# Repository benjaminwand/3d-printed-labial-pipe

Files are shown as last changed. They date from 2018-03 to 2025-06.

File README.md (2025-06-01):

# 3d-printed labial pipe

This is a collection of FreeCAD and OpenSCAD files that will help you to 3D-print a part of a labial pipe, to be used with a piece of tube. 

## Howto
This is how to go from here:
1. pick a file
2. choose and add measurements
3. export .stl
4. print. 

### Versions
Not necessarily the latest file is the one you want. Every 0.x has distinct features and then follow bugfixes. Please look at the images below to choose a pipe you want.

0.1 First attempt for pipes with 60mm diameter, made with tinkercad.com , here for sentimental reasons <br>
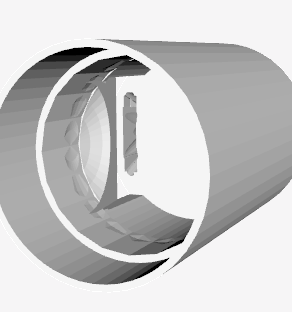
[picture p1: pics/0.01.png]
<br>
0.2 Fully proportional pipe part as FreeCAD file <br>
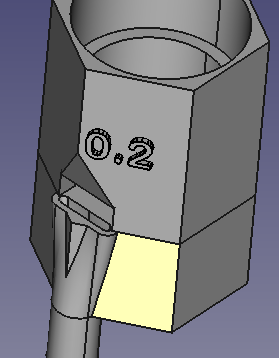
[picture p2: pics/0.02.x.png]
<br>
0.2.3 Bug fixes, mostly for cases of very narrow labium <br>
0.3 has (along the pipe) curved labium <br>
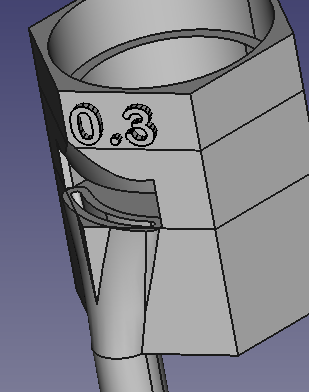
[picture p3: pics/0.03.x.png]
<br>
0.3.1 Curved labium pipe with minor bugfixes <br>
0.3.3 bugfix, sounds much better <br>
0.4.1 creative approach that did not work <br>
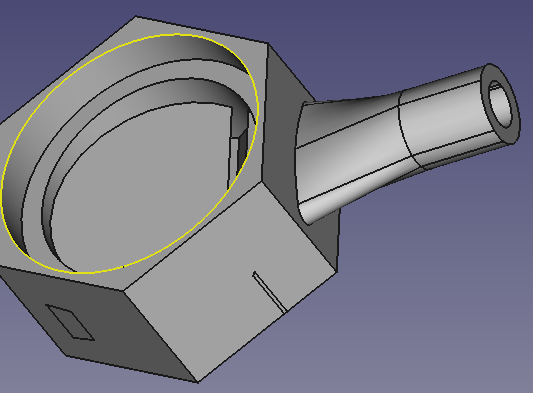
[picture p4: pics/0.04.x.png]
<br>
0.4.2 now it makes tiny tones :) <br>
0.5 Back to straight labium, better proportions, especially for wide labium, and it is hollow in the ‘block’. Surprise: the labium doesn’t need to be at the end of the sounding tube in a flue <br>
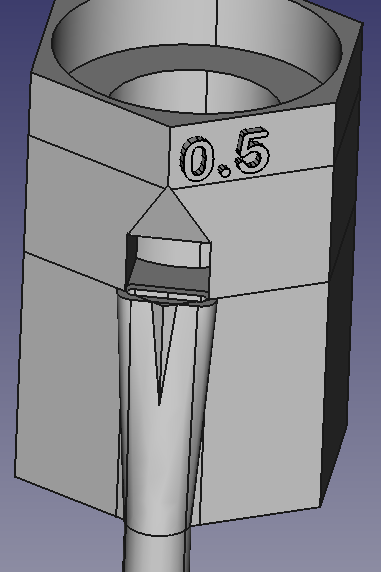
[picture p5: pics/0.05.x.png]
<br>
0.5.1 like 0.5 but more flue pipe like outer shape <br>
0.6 Experimental shape for the purpose of dividing long tubes, so far I can’t make sense of the pitch that comes out but it does sound nice <br>
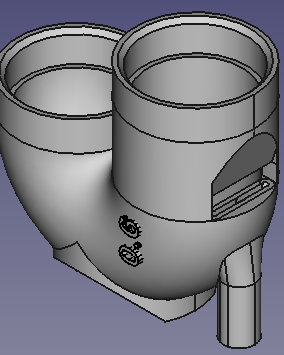
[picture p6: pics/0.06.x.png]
<br>
0.7 like 0.5 with optional block chamfer <br> 
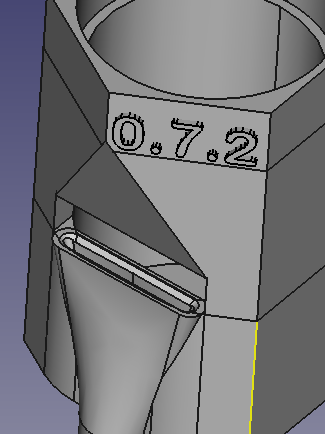
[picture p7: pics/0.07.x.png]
<br>
0.7.1 bugfix <br>
0.7.2 like 0.7.1 but more flue pipe like outer shape <br>
0.8 has ears and optional block chamfer <br> 
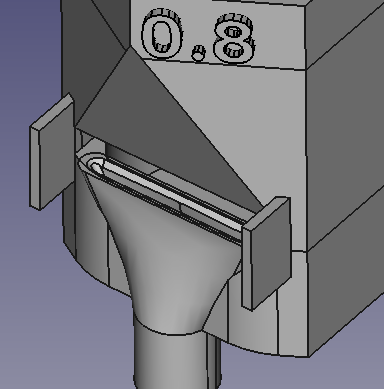
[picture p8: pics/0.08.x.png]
 <br>
0.9 has boxbeard  and optional block chamfer <br> 
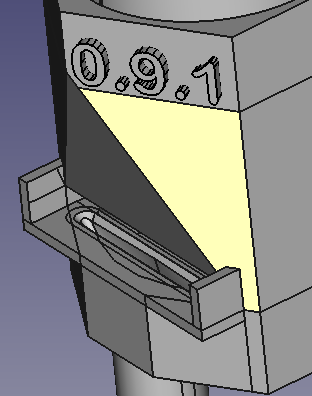
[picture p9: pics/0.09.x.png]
<br>
0.9.1 like 0.9 but more flue pipe like outer shape <br>
0.10 experimental transverse flute <br> 
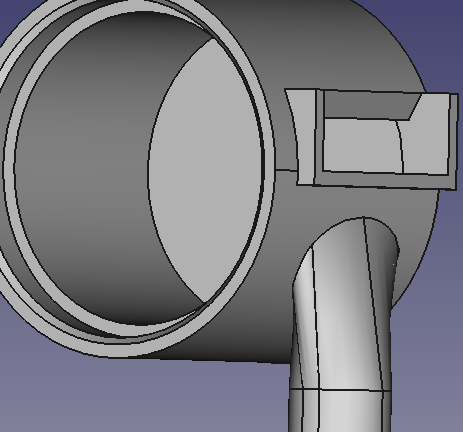
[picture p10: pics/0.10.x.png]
 <br>
0.10.4 most elegant 0.10.x<br>
0.10.5 has adjustable labium angle <br>
0.11 experimental transverse flute with different geometry <br> 
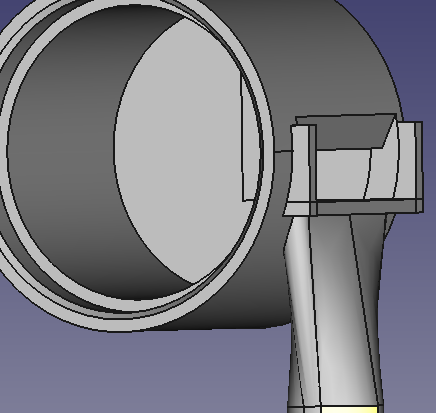
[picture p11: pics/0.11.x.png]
<br>
0.11.3 alternative <br>
0.11.4 most elegant 0.11.x <br>
0.11.5 has adjustable labium angle <br>
0.12 ‘the owl’ flute with two tubes <br> 
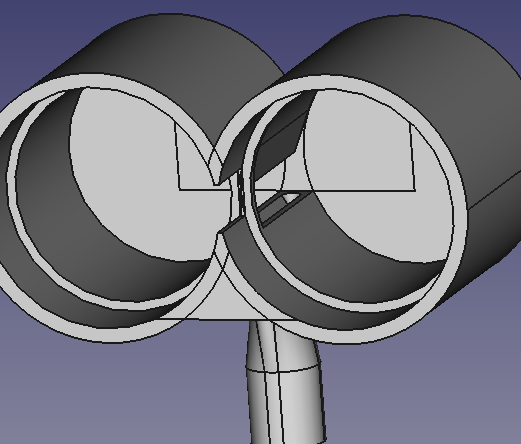
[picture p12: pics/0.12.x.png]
<br>
0.12.4 most elegant 0.12.x <br>
0.12.5 has adjustable labium angle <br>
0.12.6 bugfix <br>
0.12.7 alternative <br>
0.13 curved labium and hollow in the bottom <br> 
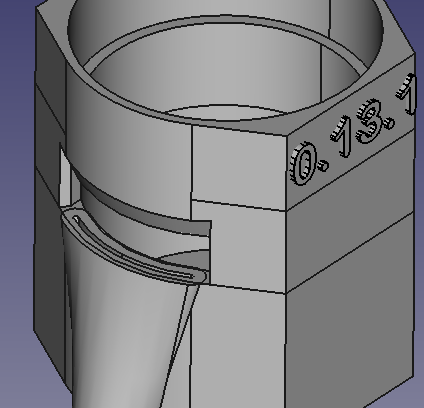
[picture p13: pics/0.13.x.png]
 <br>
0.14 new experimental traverse flute <br> 
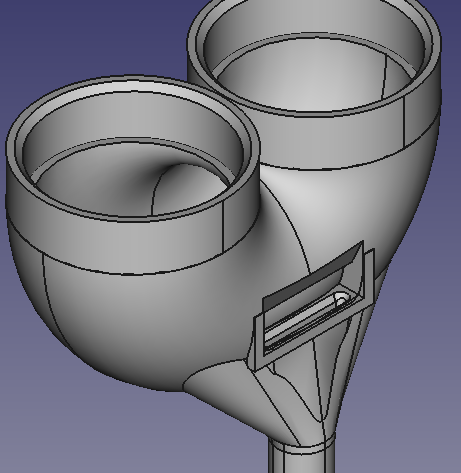
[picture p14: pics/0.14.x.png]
 <br>
0.14.2 bugfix for larger pipes <br>
0.15 pipe with 45° (diagonal) labium, for the purpose of easier slicing <br> 
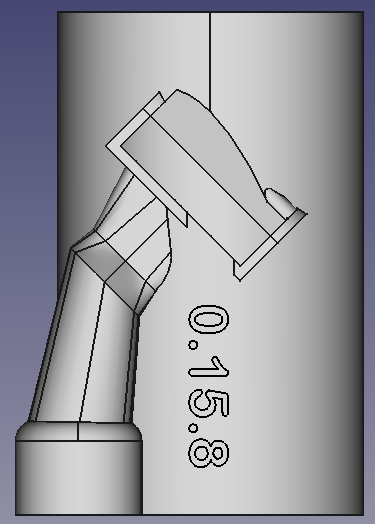
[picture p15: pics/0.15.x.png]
 <br>
0.15.1 - 0.15.9 several ways of 45° labium <br>
0.16 like 0.5 but has nicks <br> 
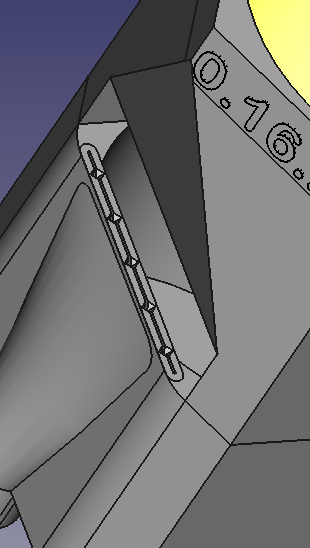
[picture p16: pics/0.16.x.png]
 <br>
0.17 curved 45° (diagonal) labium <br>
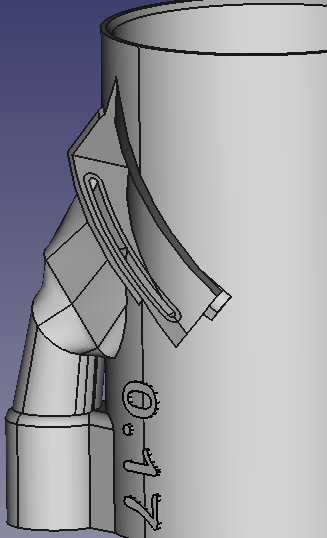
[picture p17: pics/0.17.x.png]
 <br>
0.18 traverse flute with nicks <br>
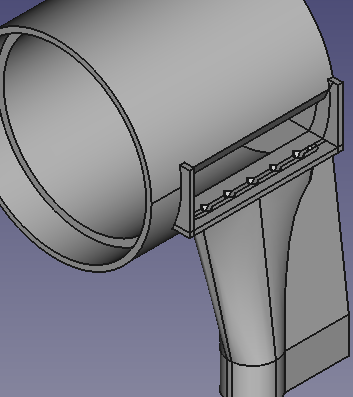
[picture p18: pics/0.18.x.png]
 <br>
0.19 angular entire flue pipe for printing upright <br>
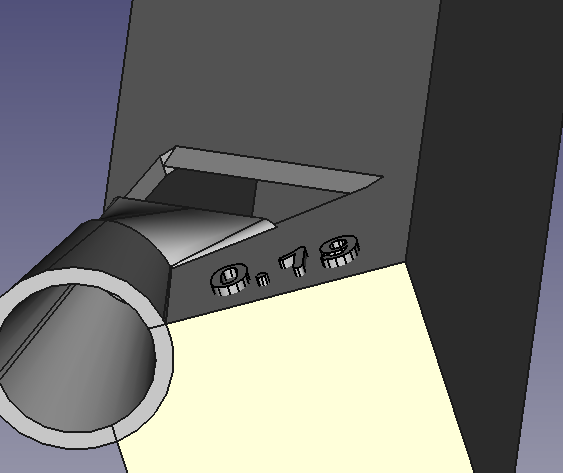
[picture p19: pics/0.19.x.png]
 <br>
0.20 flue pipe with adjustable labium angle <br>
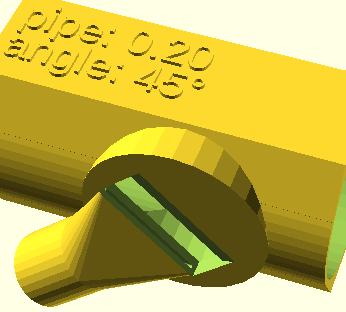
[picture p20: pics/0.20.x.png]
 <br>
0.21 traverse pipe with air supply from below <br>
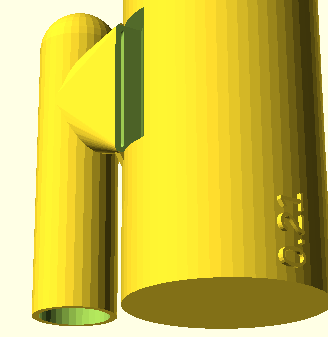
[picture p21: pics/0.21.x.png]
 <br>
0.22 pipe with 360° labium that prints in one piece <br>
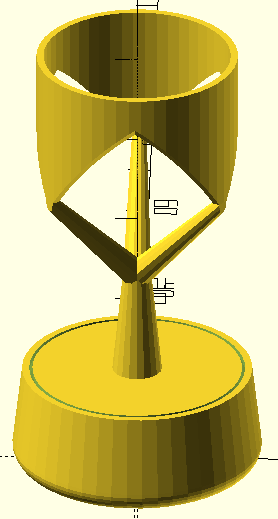
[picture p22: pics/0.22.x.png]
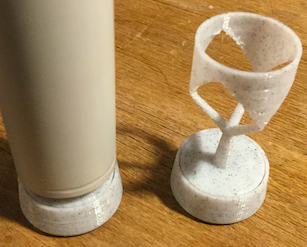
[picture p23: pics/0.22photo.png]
  <br>
0.23 pipe with 360° labium that prints in two pieces, please use a screw to connect them <br>
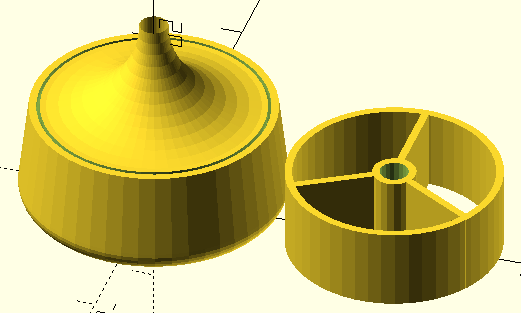
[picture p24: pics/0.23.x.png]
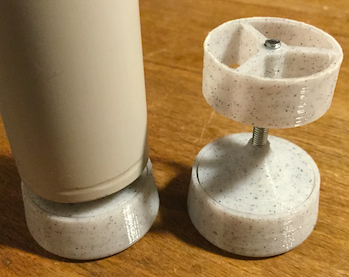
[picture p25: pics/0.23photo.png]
  <br>
0.24 pipe with 360° labium that prints in two pieces and also prints the labium <br>
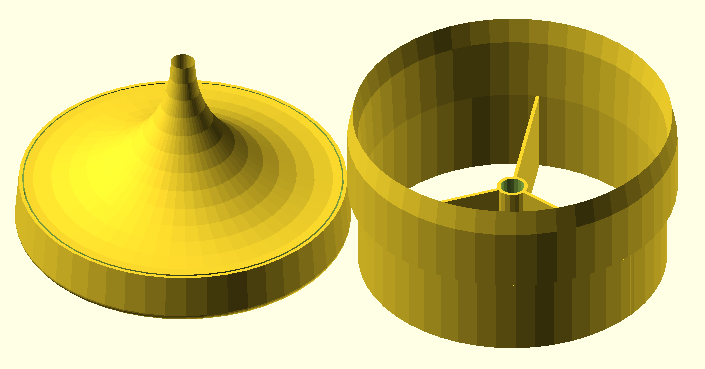
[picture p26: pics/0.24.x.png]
 <br>
0.24 pipe with 45° (diagonal) labium (similar to 0.15) but looking like a slightly squashed beverage can <br>
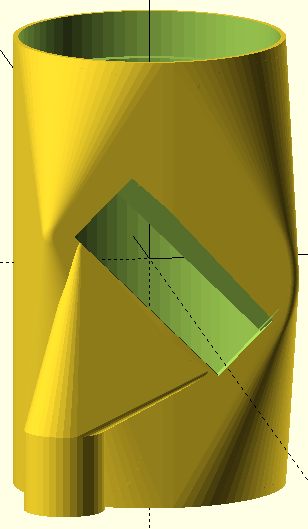
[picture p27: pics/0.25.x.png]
 <br>

[THe 360° files (0.22 - 0.24) got their own blog article.](https://benjaminwand.github.io/verbose-cv/projects/flauto_mirabilis.html)

[There are reversed free reed pipes as well.](https://github.com/benjaminwand/3d-printed-reversed-free-reed-pipe)

[And there are diaphone pipes.](https://github.com/benjaminwand/3d-printed-diaphone-pipe)

### choosing measurements
Picking the exact measurements for organ pipes is an advanced subject that includes experience and opinion. If you don’t know where to start, [webpipecalc](https://www.ccoors.de/webpipecalc/) can help. You are limited by the diameters of the tubes you can buy. ‘Diameter’ in webpipecalc means inner diameter of the tube.

You can avoid picking measurements (other then for your pipe, which is given) by choosing file 0.22 or 0.23 because they don’t have cut up and labium width measurements.

### adding measurements and exporting .stl
Please add the desired measurements into the spreadsheet (FreeCAD) or ‘variables’ section (OpenSCAD). If you are unfamiliar with both FreeCAD and OpenSCAD and just want an .stl file [you can find them amongst my Thingiverse publications.](https://www.thingiverse.com/bettercallitart/designs) I’ve also made [an introduction video for using the FreeCAD and OpenSCAD files in this repository.](https://youtu.be/g_tp1z9HByQ)

Some OpenSCAD files require at least Version 2018.

### printing
For most pipes I got the best printing results when slicing at a 45° angle and ‘support touching build plate’, so that there is no support structure under the labium. <br>
https://cdn.thingiverse.com/renders/2a/03/54/e3/72/e935fcfeddd0d054e9dca2f05e988bd0_preview_featured.jpg<br>
Some pipes (0.10, 0.11, 0.12, 0.15, 0.17, 0.18, 0.19, 0.21, 0.22, 0.23) should be printed in normal orientation though.

## Design thoughts
I was pondering the design of flue pipes from wood and metal, and came to the conclusion that the design has a lot to do with the material. Wooden pipes are built angular because that is easier than woodturning, and metal pipes are made in a round shape because less soldering. So, what would be a good design for 3D-printing? Well, something with a flat base would be handy. But then, most 3D-printers can’t print large enough for most organ pipes, organ pipes get really large you know. So I decided to use tubes from the hardware store and only 3D-print the intricate part, therefore the 3D-printed organ pipes would be round. I made the outside of many pipes hexagonal because that offers the best ratio of stability vs. little space consuming. <br>
Initially, in order to be compatible with organ builders (and people who work with wood in general), the foot was round like in wooden organ pipes, so it would be compatible with a somewhat traditional wind-chest design. Later I went for designs where one could stick in a pipe. Which can be a short pipe as well and then it fits a wind chest again. <br>
However, I don’t think it is necessary to have the foot in the middle of the cup, having it off, like in a recorder, made the design easier (I was thinking of getting the support structure removed after printing) while I couldn’t find substantial disadvantages. Also it enabled pipes that were hollow below the labium, which means the generator can be somewhere in the resonator.

In the later works (0.20 and onwards) I got playful out of enjoyment for 3d modeling.

## More online info about flue pipes (German only)
http://www.arndt-bruenner.de/hausorgel/CalcMens.htm <br>
http://www.orgel-info.de/Mensuren.pdf <br>
https://de.wikipedia.org/wiki/Orgelpfeife#Intonation <br>
http://orgelromantik.aeoline.de/2009/02/06/uber-labien-aufschnitte-und-kerne-der-labialpfeifen/ <br>
http://orgelromantik.aeoline.de/2009/12/02/die-zehn-wichtigsten-tabellen-zu-pfeifenmasen/ <br>
http://orgelromantik.aeoline.de/2011/01/14/orgel-stimmen-mit-dem-ipad/ <br>

## Spektrogramm
Looking at what you are doing (mac): <br>
    ffmpeg -f avfoundation -i ":0" -lavfi showspectrum=s=1440x900:slide=rscroll -c:v rawvideo -r 25 -pix_fmt yuv420p -f matroska - | mpv -
<br>
or
<br>
    ffmpeg -f avfoundation -i ":0" \
    -lavfi showspectrum=s=1440x900:slide=rscroll \
    -pix_fmt yuv420p -f rawvideo -r 25 - | \
    mpv --demuxer=rawvideo --demuxer-rawvideo-w=1440 --demuxer-rawvideo-h=900 --demuxer-rawvideo-fps=25 --demuxer-rawvideo-mp-format=yuv420p -
<br>
or
<br>
    ffplay -f avfoundation -i ":0" -vf showspectrum=s=1440x900:slide=rscroll
<br>
Linux: 
    ffplay -f pulse -i "default"

## other files
### flue and labium only
To figure out the generator sound/frequency <br>
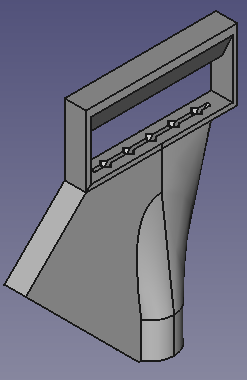
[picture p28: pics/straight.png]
 <br>
### tuning and misc
Parametric tuning devices, [some of which got their own blog article.](https://benjaminwand.github.io/verbose-cv/projects/introducing_tuning.html)

## state of the project
At some point I became tired of deploying the latest features into all files, if you want a pipe with specific features, please file a GitHub issue. I’m somewhat motivated to make OpenSCAD files of pipes that so far only exist as FreeCAD version, tell me which one you want. I’m not motivated in the opposite direction.

I’m happy to answer questions.

I'd be happy to hear about your instrument!

Licensed under CC-BY <br>
https://creativecommons.org/licenses/by/4.0/legalcode

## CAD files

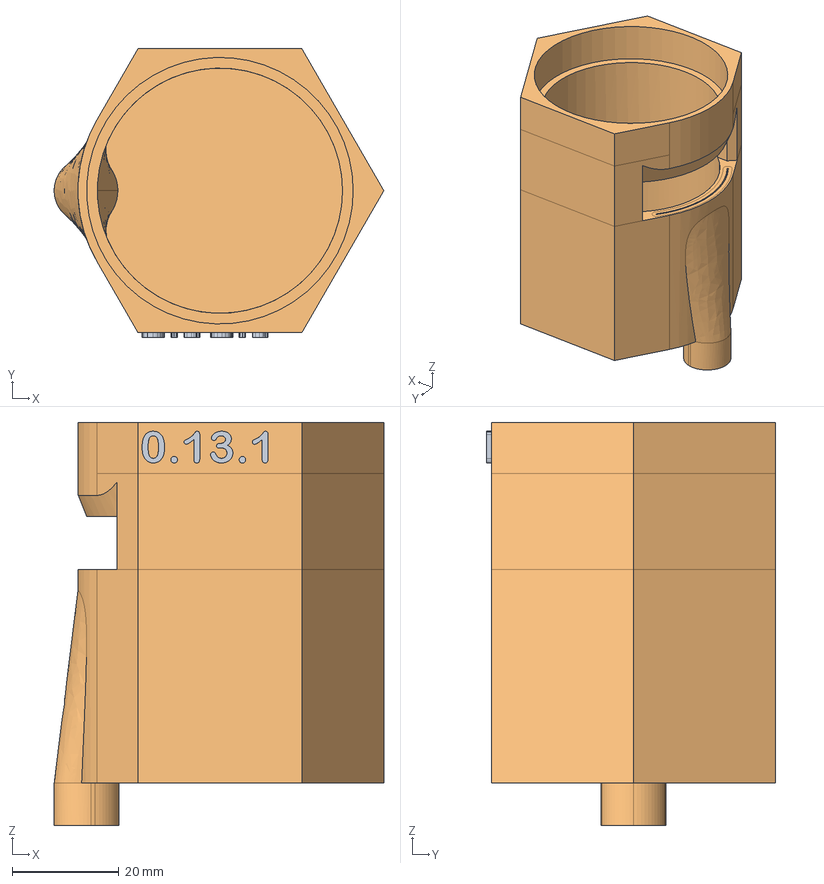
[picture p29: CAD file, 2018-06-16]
0.13.1.FCStd
61.9 x 54.1 x 75.6 mm
Fusion whole thing

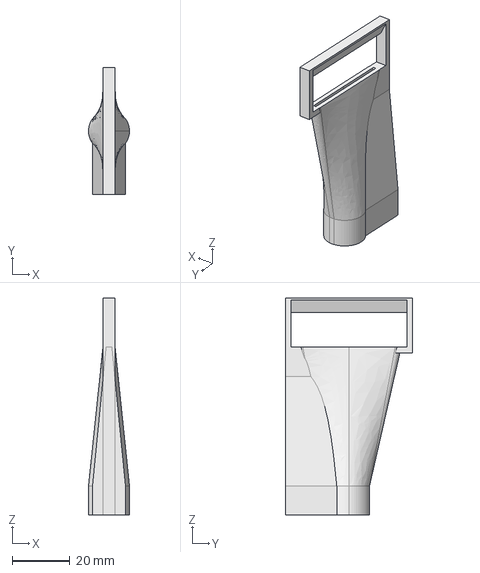
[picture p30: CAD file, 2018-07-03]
flue and labium only/straight-3.FCStd
14.2 x 44.0 x 75.0 mm

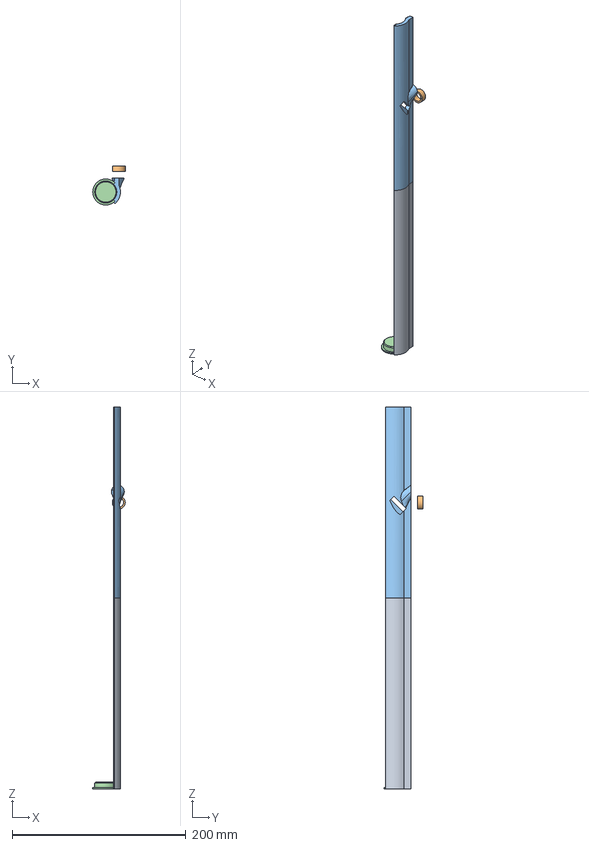
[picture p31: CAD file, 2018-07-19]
generator placement tester/cylindrical/generator plaxement test diagonal.FCStd
37.5 x 45.0 x 440.0 mm
print twice
print once as well
Fillet print once
gedackt-Plug

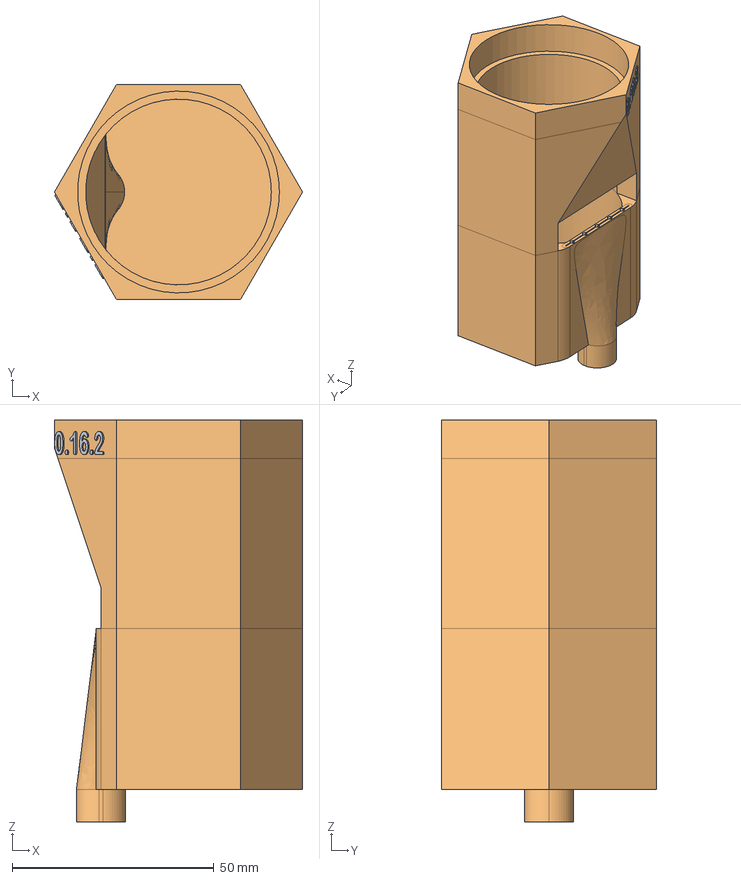
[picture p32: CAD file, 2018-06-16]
0.16.2.FCStd
61.5 x 53.3 x 99.6 mm
Fusion whole thing

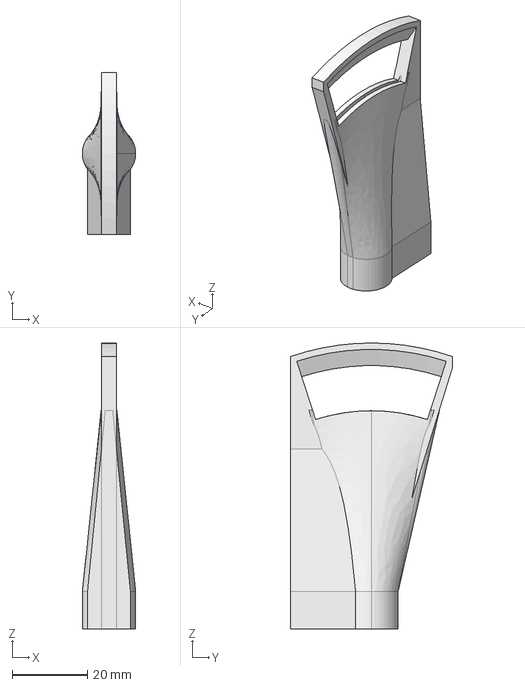
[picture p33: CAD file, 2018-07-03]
flue and labium only/sad2.FCStd
14.2 x 43.0 x 76.0 mm

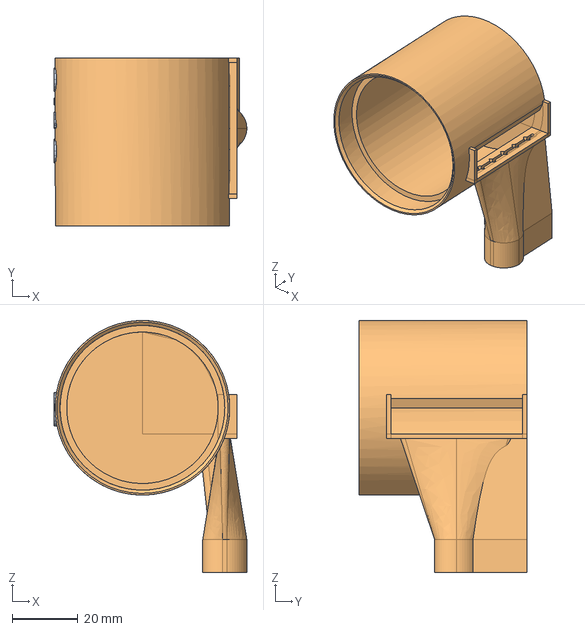
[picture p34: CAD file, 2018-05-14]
0.18.FCStd
58.5 x 50.9 x 76.5 mm
version number
Cut whole thing

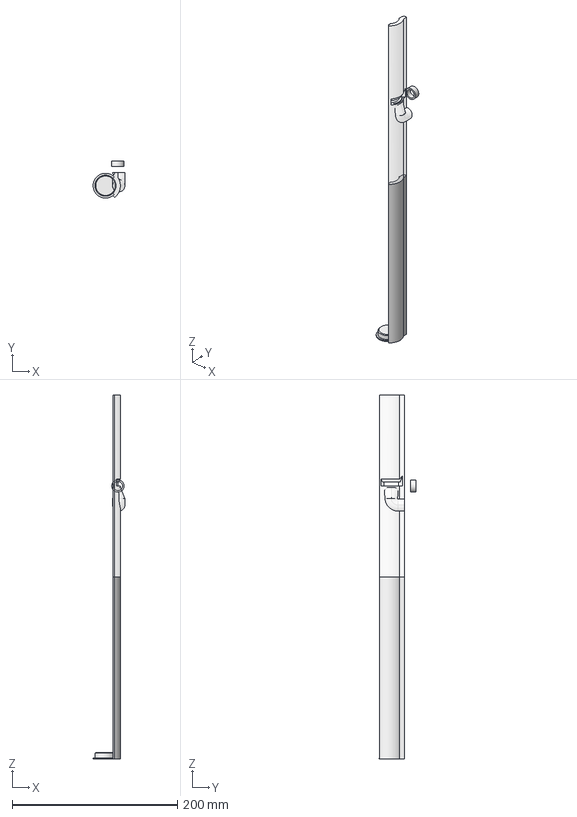
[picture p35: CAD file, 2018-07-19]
generator placement tester/cylindrical/generator placement tester length-flute.FCStd
38.5 x 45.0 x 440.0 mm
print twice
print once
print once as well
gedackt-Plug

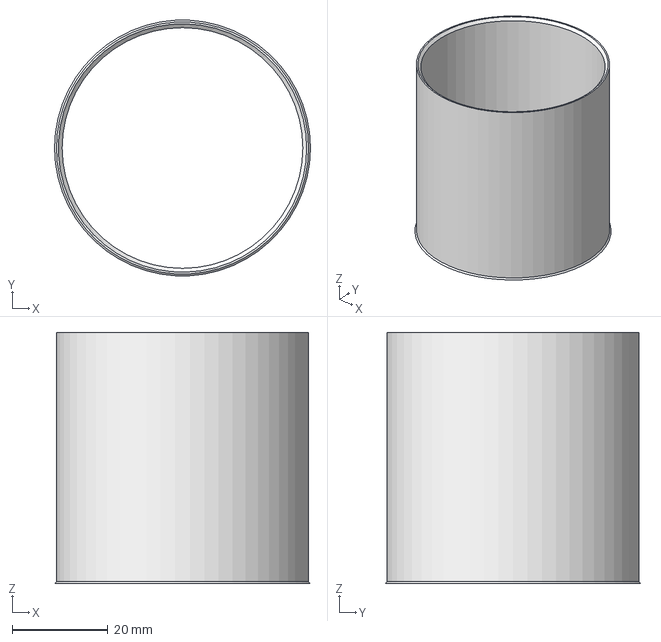
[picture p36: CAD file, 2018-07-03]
tuning and misc/tuning slider.FCStd
53.4 x 53.3 x 52.4 mm

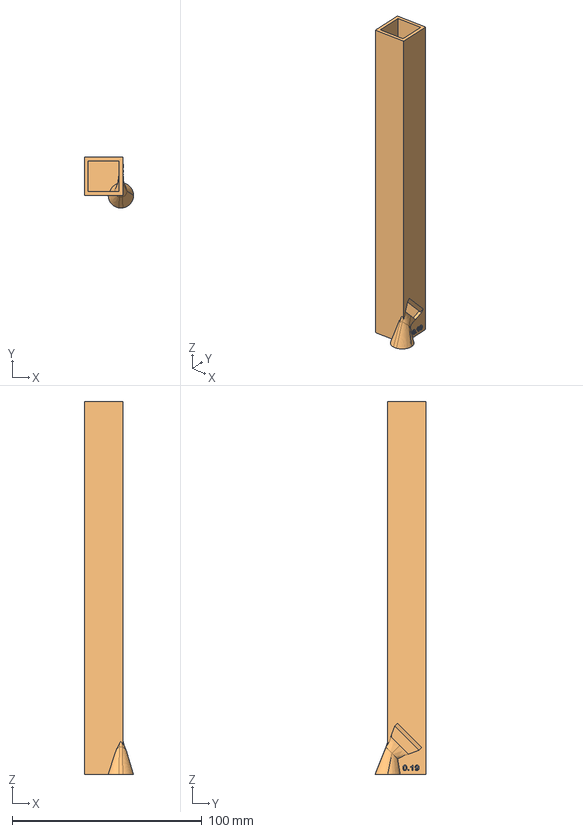
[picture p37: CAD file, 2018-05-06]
0.19.FCStd
25.9 x 26.9 x 196.6 mm
version number
Cut whole thing

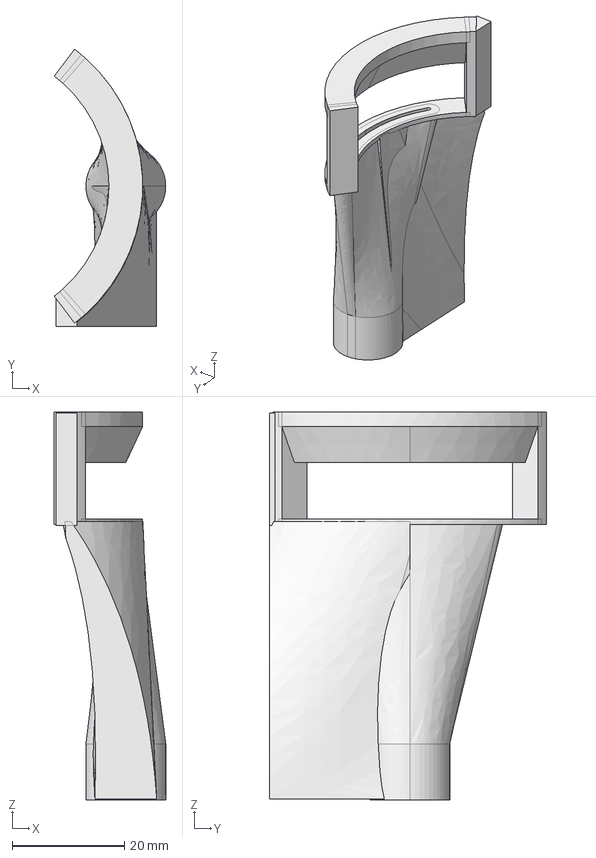
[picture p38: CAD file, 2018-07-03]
flue and labium only/curved-4.FCStd
19.8 x 49.3 x 69.0 mm

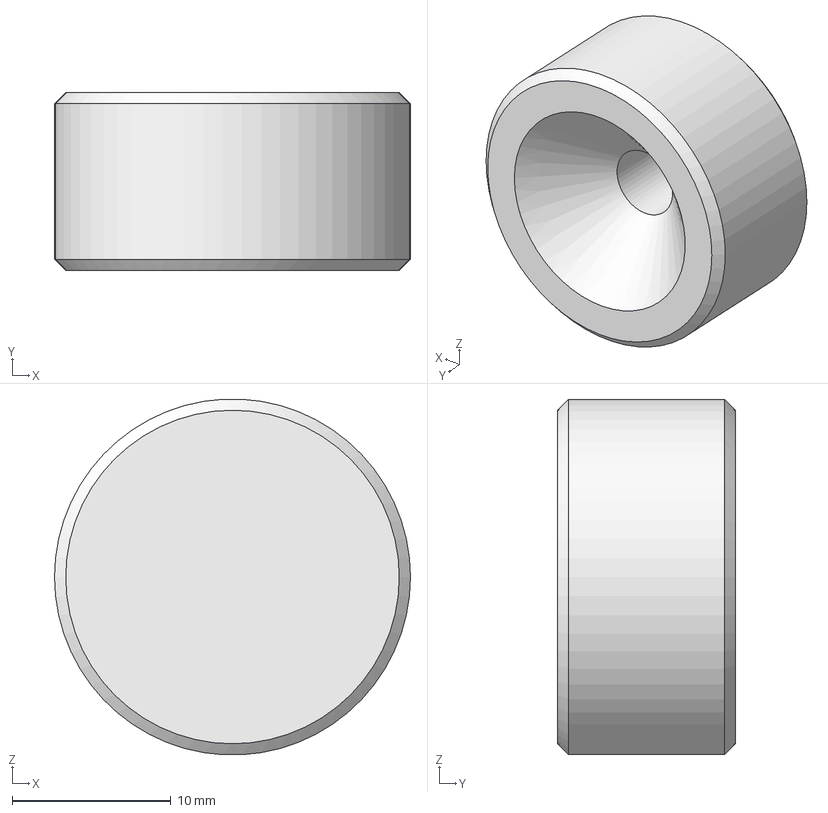
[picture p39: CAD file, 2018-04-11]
tuning and misc/slider inside.FCStd
22.4 x 11.2 x 22.4 mm

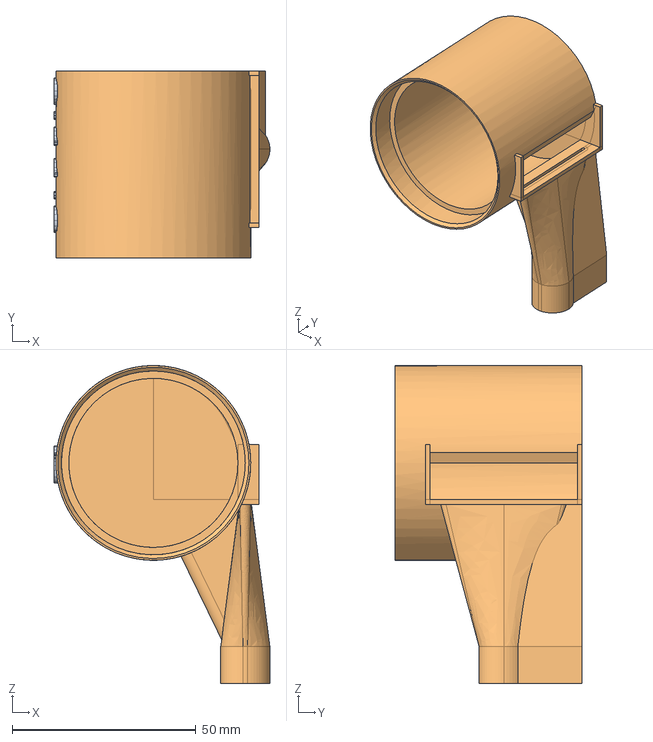
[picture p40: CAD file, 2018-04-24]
0.11.6.FCStd
58.7 x 50.9 x 86.5 mm
version number
Cut whole thing

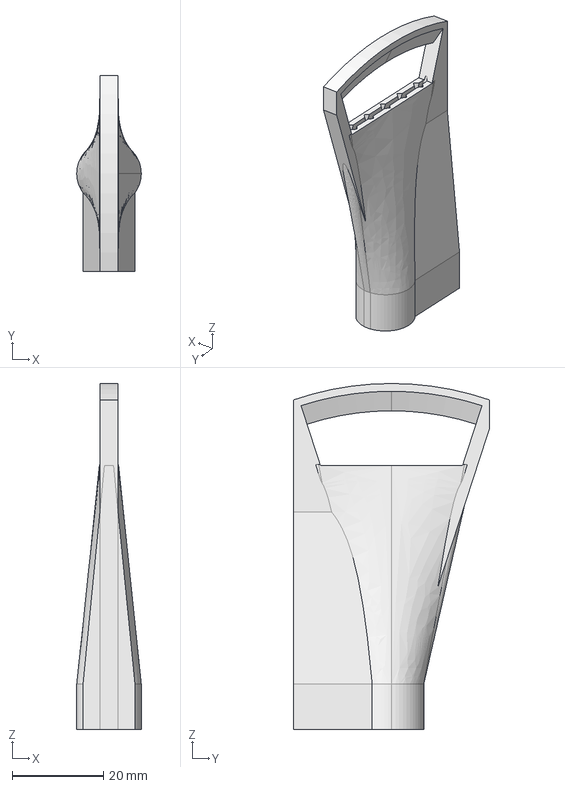
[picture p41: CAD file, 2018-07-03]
flue and labium only/sad+nicks.FCStd
14.2 x 43.0 x 76.0 mm

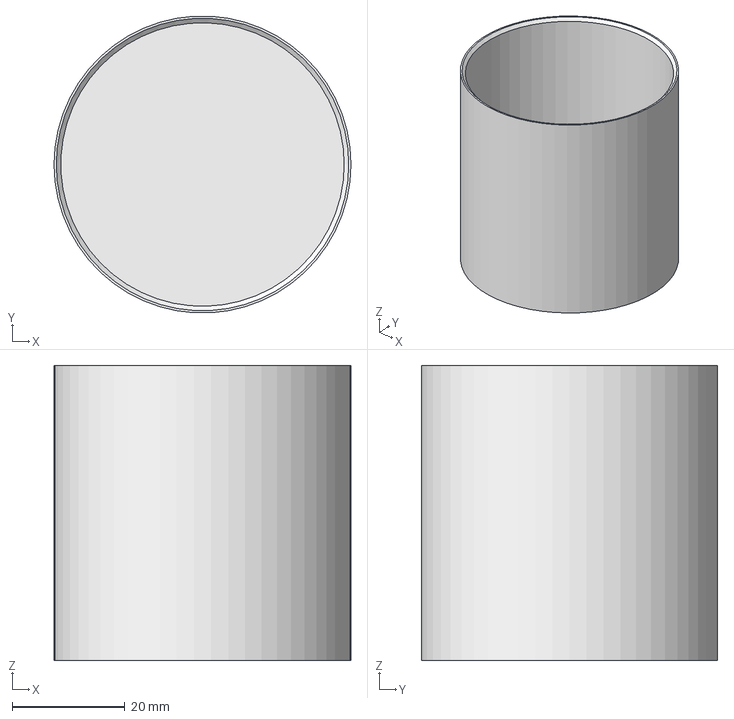
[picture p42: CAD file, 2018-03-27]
tuning and misc/tuning lid.FCStd
52.6 x 52.5 x 52.3 mm

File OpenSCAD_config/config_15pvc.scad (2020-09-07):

// pipe
outerDiameter = 15.3;     
innerDiameter = 13.3;

//air tube
tube = 6.5;          // should be at least as thick as screw head

// screw
screwDiameter = 1.9;
screwHeadDiameter = 4; // be a bit generous here / round up
screwHeadHeight = 1.3;

// pipe specifics
minWallThickness = 0.8;
minAirway = 1.5;
flueWidth = 0.3;

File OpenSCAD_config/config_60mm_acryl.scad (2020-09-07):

// pipe
outerDiameter = 60;     
innerDiameter = 55.1;

//air tube
tube = 18;          // should be at least as thick as screw head

// screw
screwDiameter = 7.9;
screwHeadDiameter = 15; // be a bit generous here / round up
screwHeadHeight = 5.7;

// pipe specifics
minWallThickness = 1.2;
minAirway = 3;
flueWidth = 0.3;

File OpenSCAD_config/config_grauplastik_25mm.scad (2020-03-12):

// pipe
outerDiameter = 25;
innerDiameter = 22.5;

//air tube
tube = 8;          // should be at least as thick as screw head

// screw
screwDiameter = 3;
screwHeadDiameter = 6; // be a bit generous here / round up
screwHeadHeight = 2;

// pipe specefics
minWallThickness = 0.8;
minAirway = 2.5;
flueWidth = 0.3;

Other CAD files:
generator placement tester/cylindrical/generator placement test traverse.FCStd
flue and labium only/sad1.FCStd
0.17.2.FCStd
flue and labium only/sad+bent.FCStd
OpenSCAD_config/config_Wasserrohr.scad
0.01 rund 60mm.stl
0.01 sechseckig 60mm.stl
0.02 proportional.FCStd
0.02.3.FCStd
0.03.1.FCStd
0.03.3.FCStd
0.03.FCStd
0.04.1.FCStd
0.04.2.FCStd
0.05.1.FCStd
0.05.2 wide labium.scad
0.05.2.scad
0.05.FCStd
0.06.FCStd
0.07.1.FCStd
0.07.2.FCStd
0.07.FCStd
0.08.FCStd
0.09.1.FCStd
0.09.FCStd
0.10.4.FCStd
0.10.5.FCStd
0.10.FCStd
0.11.3.FCStd
0.11.4.FCStd
0.11.5.FCStd
0.11.7.scad
0.11.FCStd
0.12.0.FCStd
0.12.4.FCStd
0.12.5.FCStd
0.12.6.FCStd
0.12.7.FCStd
0.13.2 sketch.scad
0.13.2.scad
0.13.3 sketch.scad
0.13.3.scad
0.13.FCStd
0.14.1.FCStd
0.14.2.FCStd
0.14.FCStd
0.15.1.FCStd
0.15.10 sketch.scad
0.15.10.scad
0.15.11.scad
0.15.12.scad
0.15.13.scad
0.15.3.FCStd
0.15.4.FCStd
0.15.5.FCStd
0.15.6.FCStd
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

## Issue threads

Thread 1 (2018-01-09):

Please add screenshots/pics to README

luzpaz, 2018-01-09:

benjaminwand, 2018-01-10:
I’m assuming that I’m addressing people here (on GitHub) who are able to install FreeCAD and look at the actual files. Everyone else can go to https://www.thingiverse.com/thing:2745939

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

luzpaz, 2018-01-10:
people search FC related things on github. But it's your call. Do you mind adding 'topics' aka tags to this repo? at least adding `freecad` ?

benjaminwand, 2018-01-10:
ok. question: why are you trying to make me do these things?

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

luzpaz, 2018-01-10:
I volunteer for FreeCAD and am trying to make searching FreeCAD related repos more search-able per se. I also keep an eye out for cool FC projects to share with the community

benjaminwand, 2018-01-10:
How do you prefer FreeCAD-Projects to be presented on GitHub, what would be a good example in your opinion?
I didn’t post images because I think they aren’t necessary in the case of this repo. Sometimes they are to make a thing clear, like this https://github.com/benjaminwand/voctoknopf1/blob/master/photos%20%26%20co/bugfixes.jpg
Organ building is an incredibly nerdy topic, if someone in into organs *and* on GitHub, I’m pretty sure they can look at the files in FreeCAD on their own.

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

luzpaz, 2018-01-10:
@benjaminwand First, Nerdy or not, it's cool and it was made using FC. I think it also merits being posted in the [User Showcase subforum](https://forum.freecadweb.org/viewforum.php?f=24).
As for a good/ideal example, I will find you one soon.

benjaminwand, 2018-01-10:
What is the purpose of the showcase forum?

Von meinem iPod gesendet

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

luzpaz, 2018-01-10:
just to give a heads up to the FC community about a project and how FreeCAD was used for it.

luzpaz, 2018-01-11:
apropos: https://forum.freecadweb.org/viewtopic.php?f=24&t=26319&p=208838#p208838

benjaminwand, 2018-01-21:
https://forum.freecadweb.org/viewtopic.php?f=24&t=26464&p=210695#p210695
Are you happy now?

benjaminwand, 2018-01-23:
It does not represent all the versions but I'm _really_ not willing to maintain a folder with screenshots of everything

luzpaz, 2018-01-23:
fair enough. cheers

Closed 2018-01-23.

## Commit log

2017-10-11 Add files via upload
    This was the first labial pipe design I made, with tinkercad.com
    [Orgelpfeifen-Fuß rund 0.1.stl, Orgelpfeifen-Fuß sechseckig 0.1.stl]
2017-10-11 Delete Orgelpfeifen-Fuß rund 0.1.stl
    I'll replace it for one with a batter file name
    [Orgelpfeifen-Fuß rund 0.1.stl]
2017-10-11 Delete Orgelpfeifen-Fuß sechseckig 0.1.stl
    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
    [Orgelpfeifen-Fuß sechseckig 0.1.stl]
2017-10-11 Add files via upload
    Uploading version 0.1 files, made with tinkercad
    [0.1 rund 60mm.stl, 0.1 sechseckig 60mm.stl]
2017-10-11 0.2
    uploading proportional organ pipe file, like promised
    [0.2 proportional.FCStd]
2017-10-18 Add files via upload
    0.2.3 and 0.3 uploaded
    [0.2.3.FCStd, 0.3.FCStd]
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2018-02-22 block camfer fix
    [0.07.1.FCStd, 0.08.FCStd, 0.09.FCStd]
2018-03-04 more traverse flutes and the owl on a happy Sunday
    [0.09.FCStd, 0.10.3.FCStd, 0.10.4.FCStd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]
2018-03-05 bug fixes with labium and block camfer
    [0.10.4.FCStd, 0.11.4.FCStd, 0.12.4.FCStd]
2018-03-05 more block camfer improvement and bug fixes
    [0.10.4.FCStd, 0.11.4.FCStd, 0.12.4.FCStd]
2018-03-05 beard hight can be adjusted
    [0.10.4.FCStd, 0.11.4.FCStd, 0.12.4.FCStd]
2018-03-11 uploading latest so thet FreeCAD forum can help me
    [0.12.3.FCStd, 0.12.5.FCStd, 0.12.6.FCStd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]
2018-03-11 has adjustable labium angle
    [0.10.5.FCStd, 0.11.5.FCStd, 0.12.6.FCStd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]
2018-03-14 minor issues
    [0.03.3.FCStd, 0.03.FCStd, 0.04.2.FCStd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]
2018-03-15 0.13: curved labium and hollow inside
    [0.03.3.FCStd, 0.13.FCStd]
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2018-03-25 bugfix for larger pipes
    [0.14.1.FCStd, 0.14.2.FCStd, 0.14.FCStd]
2018-03-27 jetzt auch mit Versionsnummer
    [0.05.FCStd]
2018-03-28 jetzt mit optionalem Versionenummern auf den Pfeifen
    [0.02.3.FCStd, 0.03.3.FCStd, 0.05.FCStd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]
2018-03-28 bugfix on 0.15
    [0.05.FCStd, 0.15.FCStd]
2018-03-30 new .15 pipes, 0.15.6 is assuming to get air through a a vinyl tube (-> pneumatic action)
    [0.14.2.FCStd, 0.15.1.FCStd, 0.15.3.FCStd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]
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2018-04-08 more usual pipe like shape
    [0.05.1.FCStd, 0.07.1.FCStd, 0.07.2.FCStd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]
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2018-04-09 more pipes with adjustable flue
    [0.05.1.FCStd, 0.07.2.FCStd, 0.08.FCStd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]
2018-04-11 minor bugfix
    [0.15.8.FCStd]
2018-04-11 more useful inside slider
    [slider inside.FCStd, tuning slider.FCStd]
2018-04-12 realities around fdm printers
    [0.05.1.FCStd, 0.07.2.FCStd, 0.08.FCStd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]
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2018-04-16 0.11.6: traverse flute to be used with tube
    [0.11.6.FCStd, 0.15.9.FCStd, 0.17.1.FCStd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]
2018-04-16 option for 'smallest slit'
    [0.11.6.FCStd]
2018-04-18 0.18: traverse flute with nicks
    [0.11.6.FCStd, 0.18.FCStd]
2018-04-21 0.19 and Schneidenton items
    [0.18.FCStd, 0.19.FCStd, curved-2.FCStd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]
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2018-04-24 1,2 mm reinpuste-Dicke, und Schneidentöne-Tester
    [0.11.6.FCStd, 0.15.9.FCStd, 0.17.2.FCStd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]
2018-05-06 another generator sound test
    [0.19.FCStd, curved-4.FCStd, straight-3.FCStd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]
2018-06-16 mehr Schneidentontests und bugfixes
    [0.13.1.FCStd, 0.16.2.FCStd, curved-4.FCStd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]
2018-06-16 minor fix
    [sad1.FCStd, sad2.FCStd]
2018-07-03 making Schneidentontester better to print and new tuning device
    [curved-4.FCStd, sad+bent.FCStd, sad+nicks.FCStd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]
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2018-07-09 breitere standfläche zum Drucken
    [generator placement tester.FCStd]
2018-07-14 more generator positioning testers
    [generator placement test traverse-flute.FCStd, generator placement tester length-flute.FCStd, generator placement tester.FCStd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]
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2018-08-29 generator placament testers moved and new parameter in tuning lid screw
    [generator placement test traverse.FCStd, generator placement tester length-flute.FCStd, generator plaxement test diagonal.FCStd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]
2018-09-11 1st openscad flute attempt
    [0.13 sketch.scad]
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2018-09-14 announcing sounding length, bugfix
    [0.13 sketch.scad]
2018-09-16 new files: common and 0.13.3
    [0.13 sketch.scad, 0.13.2 sketch.scad, 0.13.3 sketch.scad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]
2018-09-17 working on the loft
    [0.13.3 sketch.scad]
2018-09-17 yay, an algorithm made polygon!
    [0.13.3 sketch.scad]
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2018-09-20 finally there is a (very broken) polyhedron
    [0.13.3 sketch.scad, test.scad]
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2018-09-21 0.13.4 sketch: alles piped jetzt durch
    [0.13.4 sketch.scad, test.scad]
2018-09-24 more examplified, actually working polyhedron
    [0.13.4.1 sketch.scad, common.scad]
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2018-10-03 less points - more good.
    [0.13.3.1 sketch.scad, 0.13.4.2 sketch.scad]
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2018-10-03 loft into organ pipe
    [0.13.4.3.scad, common.scad]
2018-10-03 adding loft.scad and kicking out files that didn't würk anyway
    [0.13.3 sketch.scad, 0.13.3.1 sketch.scad, 0.13.4 sketch.scad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]
2018-10-04 three actual pipes in OpenSCAD: 0.5.2, 0.13.2, 0.13.3
    [0.13.2.scad, 0.13.3.scad, 0.5.2.scad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]
2018-10-06 wide and narrow labium files for 0.5.2
    [0.05.2 narrow labium.scad, 0.05.2 wide labium.scad]
2018-10-06 loft is funny for some numbers (bug?)
    [0.13.3.scad]
2018-10-06 conditional for labium width
    [0.05.2 narrow labium.scad, 0.05.2.scad, toy Kopie.scad]
2018-10-06 bugfix for wide labium
    [0.05.2.scad, straight_flue.scad]
2018-10-06 bugfix on straight labium fill
    [0.05.2.scad, straight_labium.scad]
2018-10-06 change height proportion to innerDiameter
    [0.05.2.scad]
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2018-10-07 version number for 0.13.2 + code prettiness for 0.13.3
    [0.13.2.scad, 0.13.3.scad]
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2018-10-11 right scope for elliptic labium and todo list
    [toy Kopie.scad]
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2018-10-13 error handling
    [0.17 sketch.scad]
2018-10-13 correct error message
    [0.17 sketch.scad]
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2018-10-13 minor bug
    [0.17 sketch.scad]
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2018-10-16 nix sketch, 0.17.3 is an OpenSCAD file now
    [0.17 sketch.scad]
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2018-10-18 correct version number
    [0.17.3.scad]
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2018-11-21 someone from codebar.io made some changes that I don't understand
    [0.17.3.scad]
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2019-03-01 airSupplyY = - outerDiameter/4 - innerDiameter/4 - minWallThickness/2; + circumfrence-tester
    [0.17.3.scad, 0.20.0.scad, Schlauchpfeife.scad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]
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2020-02-28 first attempt for flauto mirabilis (Kuhn) / Vox Maris (Hey), not printed and tested yet
    [0.05.2.scad, 0.22.0 flauto mirabilis (Kuhn).scad]
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2020-03-05 trying design change in 0.22 for easier print, publishing 0.23
    [0.23.0.scad]
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2020-03-05 pics of 0.22 and 0.23 and updated readme
    [0.22.0 flauto mirabilis (Kuhn).scad, 0.23.0.scad]
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2020-03-08 stuckIn implemented
    [0.23.0.scad]
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2020-03-11 otherwise it won't fit
    [0.24.0.scad]
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2020-04-08 New tuning devices, written in OpenSCAD, and they even work!
    [0.24.0.scad, Tuning_cap_with_Mscrew.scad, Tuning_slider_with_Mscrew.scad]
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2020-04-09 new 'height' calculation, new connector, new cap/slider height
    [0.21.0.scad, Tuning_cap_with_Mscrew.scad, Tuning_slider_with_Mscrew.scad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]
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2020-09-05 fixed curve and code style
    [0.15.13.scad, common.scad]
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
